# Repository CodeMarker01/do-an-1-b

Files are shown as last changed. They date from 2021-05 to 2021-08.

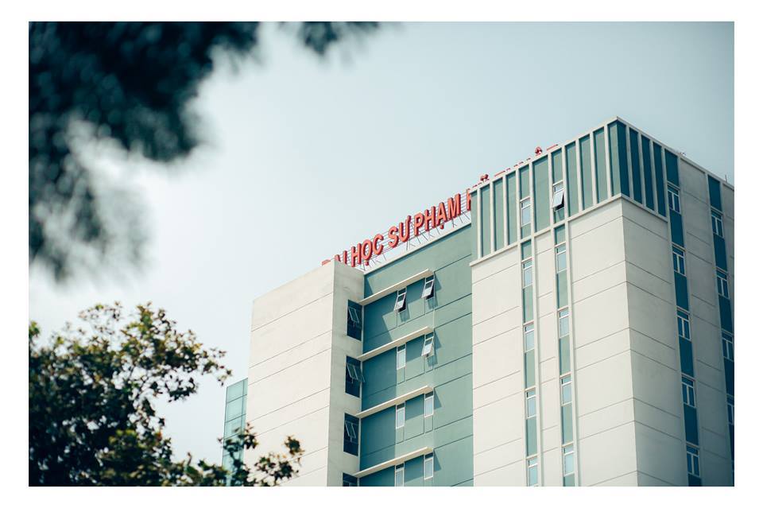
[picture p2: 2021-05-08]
Design HMI/Picture/a/UTE/SPKT1.jpg

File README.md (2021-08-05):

# ĐỒ ÁN TỐT NGHIỆP - PHẠM NHẤT SINH - TRẦN ĐĂNG QUANG
/** Thiết kế và thi công hệ thống chấm công nhân viên **/

1. Source Code phần nhúng: Embedded/Code/DATN_V3_DONE
2. File thiết kế giao diện màn hình HMI: Design HMI/Design/DATN.HMI
3. File thiết kế board mạch: Design Hardware/Design/Source.docx
4. File thiết kế mô hình: Design Model/DATN_sinhquang.dxf
5. File Sever: server
6. Source code phần Web: client

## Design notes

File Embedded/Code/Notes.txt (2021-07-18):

1. R305 giao tiếp ESP32 qua UART2: sửa lại TX: 2 - RX: 4 (trong HardwareSerial.cpp).
2. HMI giao tiếp ESP32 qua UART1: sửa lại nextionSerial: Serial1 (trong NextionCong).
				  xóa nexupdate trong lib nextion

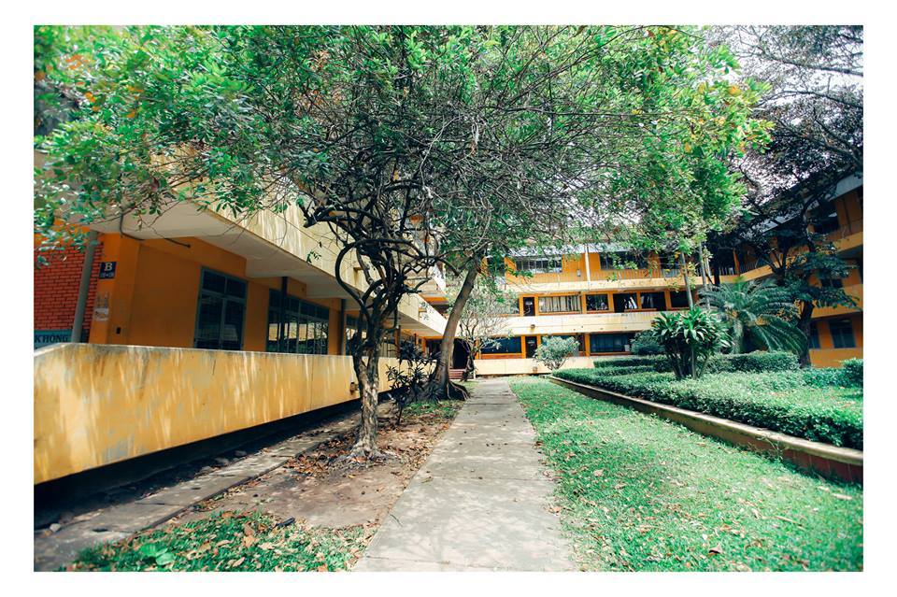
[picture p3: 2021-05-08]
Design HMI/Picture/a/UTE/SPKT5.jpg

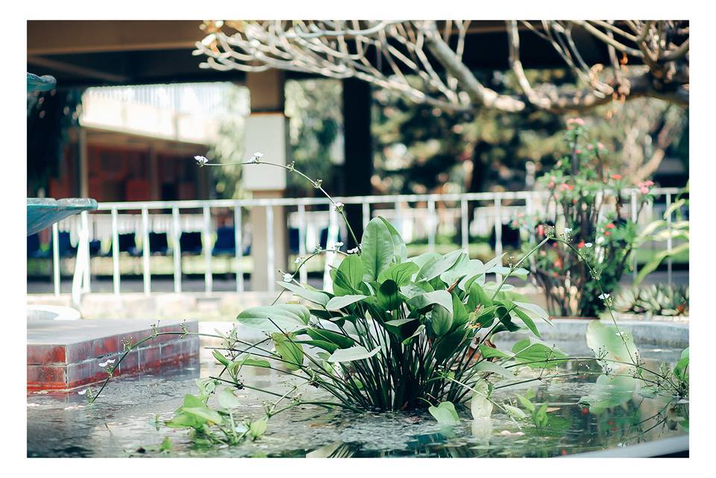
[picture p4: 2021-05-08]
Design HMI/Picture/a/UTE/SPKT2.jpg

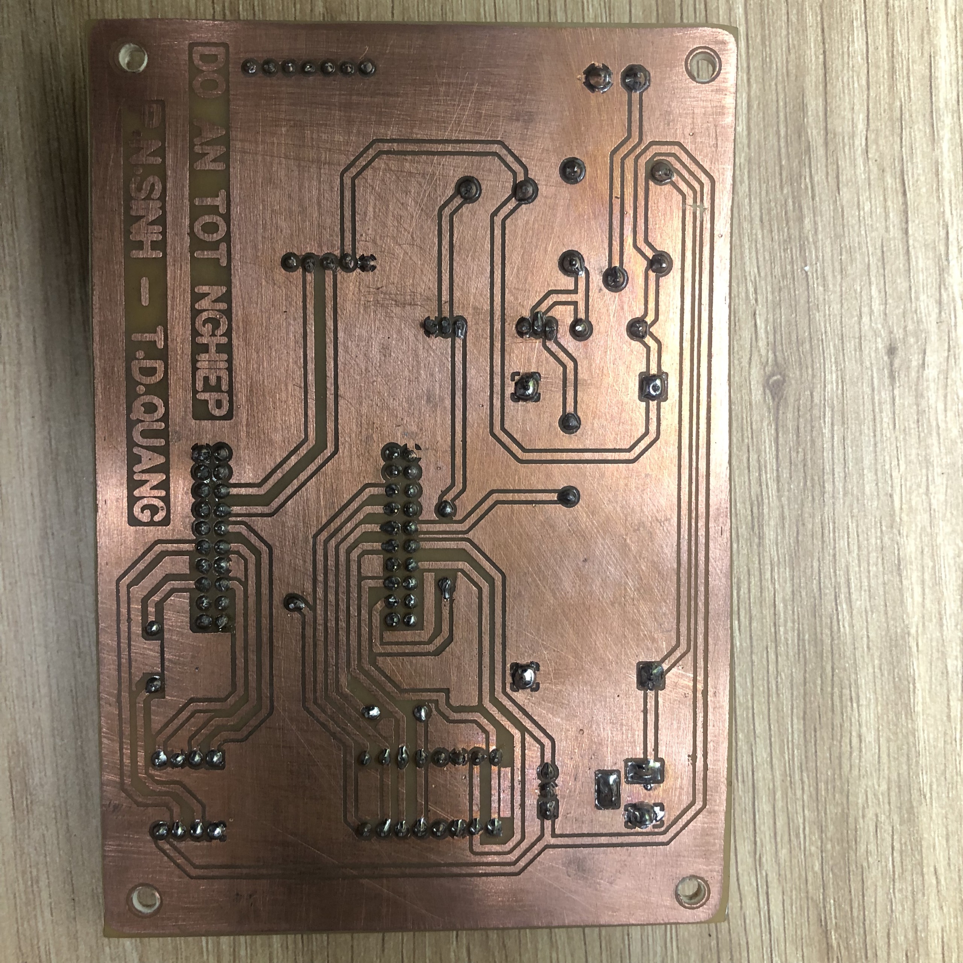
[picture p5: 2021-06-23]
Design Hardware/Image/Actual image/z2544616520501_a6df848a63fc4f655f9d95091a193955.jpg

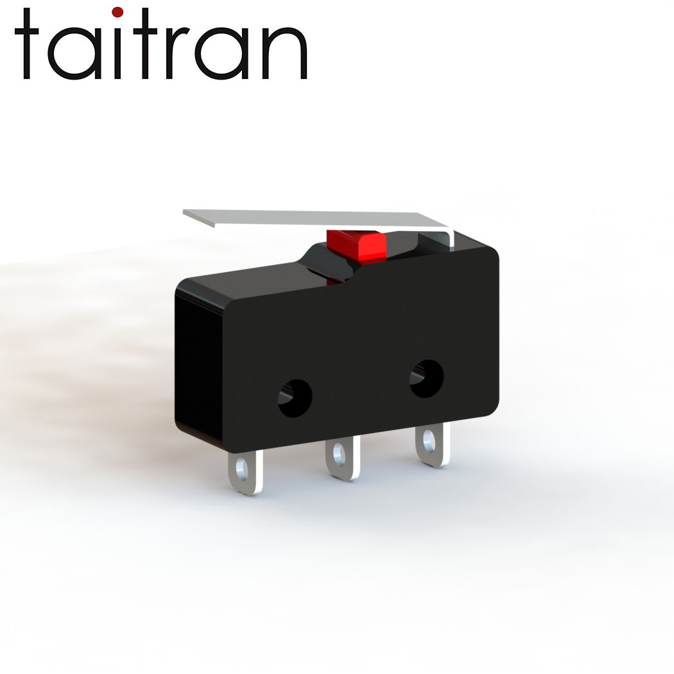
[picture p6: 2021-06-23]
Design Model/Size Module/File 3D module/Picture/cong tat hanh trinh.JPG

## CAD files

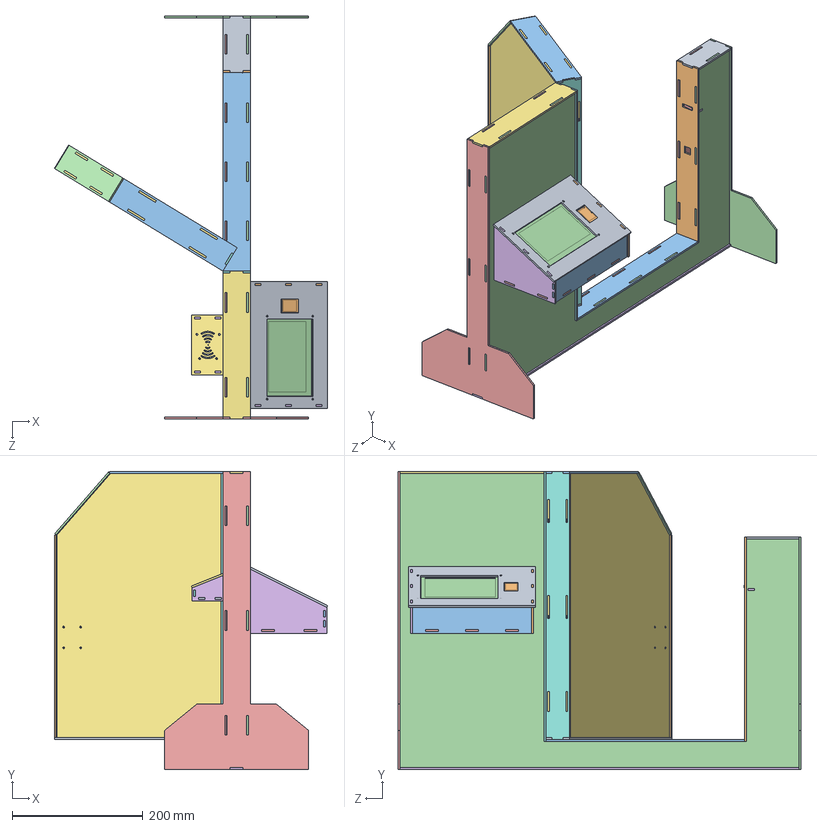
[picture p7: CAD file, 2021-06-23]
Design Model/Autocad/H.SLDASM
418.3 x 456.0 x 616.0 mm
H_mattruoc
H_mathongphai
H_matdoidien
Khungcua_vachtruoc
H_matday
Khungcua_vachday
Khungcua_vachtren
Khungcua_vachcuahongtrai
Khungcua_vachtrennho
Khungcua_vachcuahongphai
Khungcua_vachduoi
Khungcua_vachhongphai
Khungcua_vachhongtrai
H_mathongtrai
cua_vachchinh x 2
cua_vachtrai
cua_vachday
cua_vachphai
cua_vachtren
cua_vachtren1
Khungcua_vachsau
HOPRFID_vachhong x 2
HOPRFID_vachtren
HOPRFID_vachtruoc
HOPRFID_vachday
cam bien van tay
RFID
man hinh nextion
congtachanhtrinh
H_partgancongtachanhtrinh

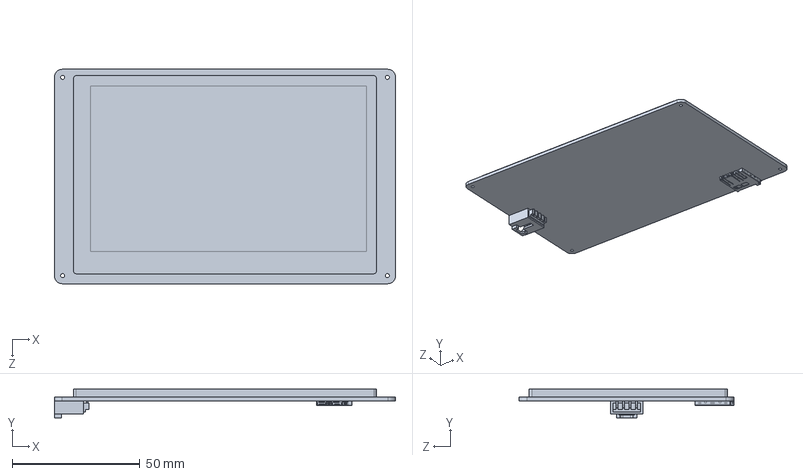
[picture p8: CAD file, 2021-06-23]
Design Model/Autocad/man hinh nextion.SLDPRT
133.5 x 11.2 x 84.0 mm

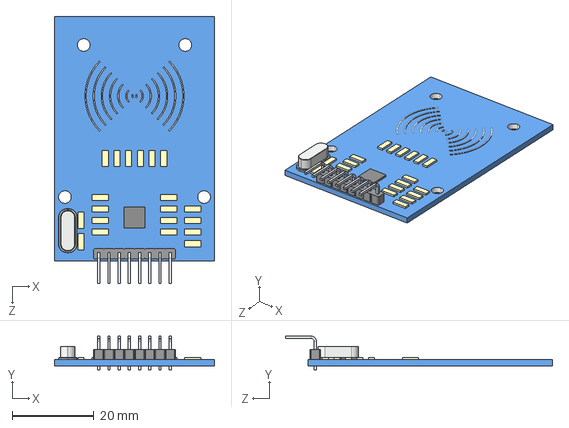
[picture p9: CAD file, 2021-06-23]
Design Model/Autocad/New folder/RC522.STEP
39.2 x 8.30 x 65.5 mm

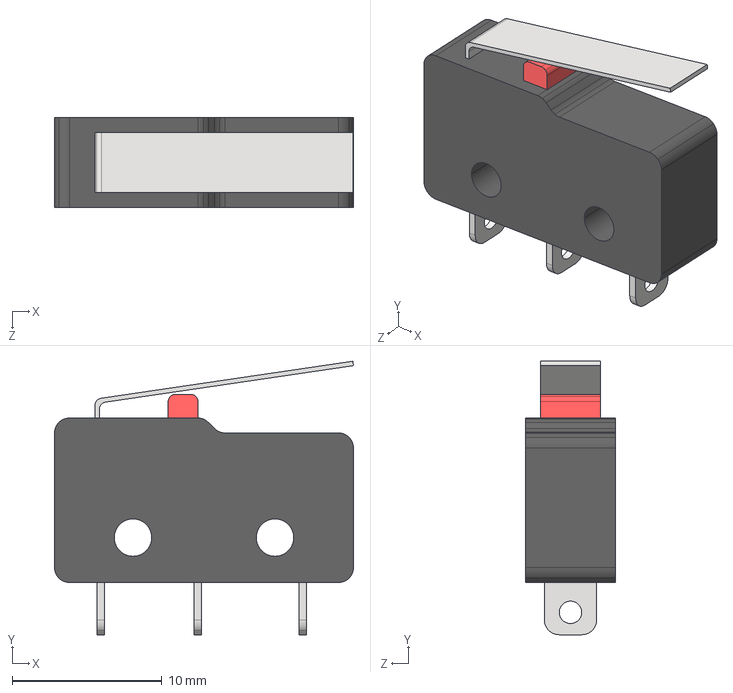
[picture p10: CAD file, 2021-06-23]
Design Model/Autocad/New folder/STEP/cong tat hanh trinh.STEP
20.0 x 18.3 x 6.00 mm

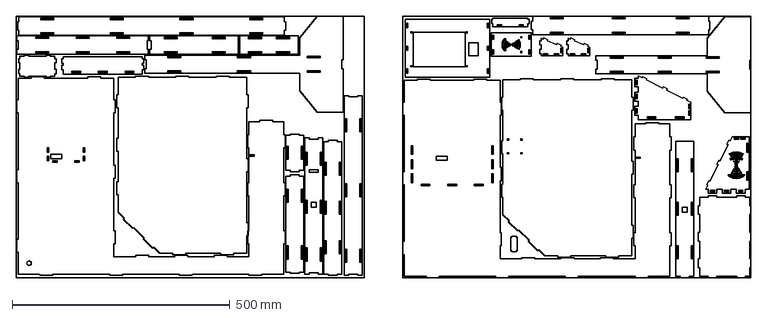
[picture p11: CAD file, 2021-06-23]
Design Model/DATN_sinhquang.dxf
1687.9 x 600.0 mm

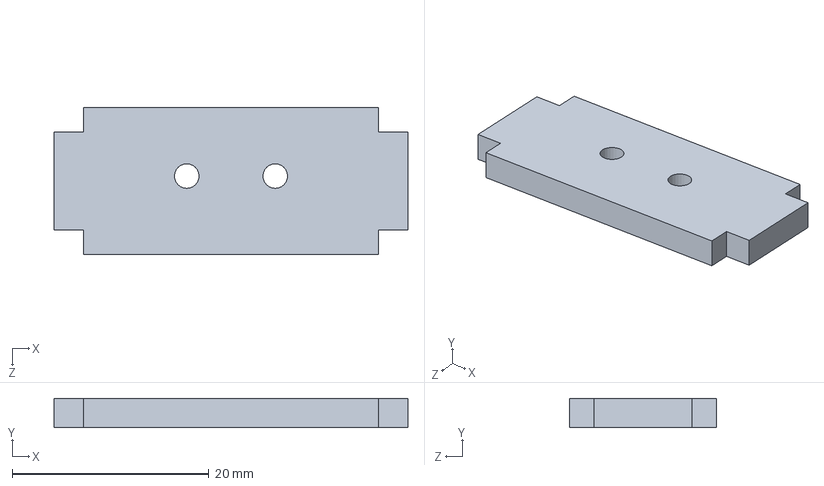
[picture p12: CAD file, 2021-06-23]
Design Model/Autocad/H_partgancongtachanhtrinh.SLDPRT
36.0 x 3.00 x 15.0 mm

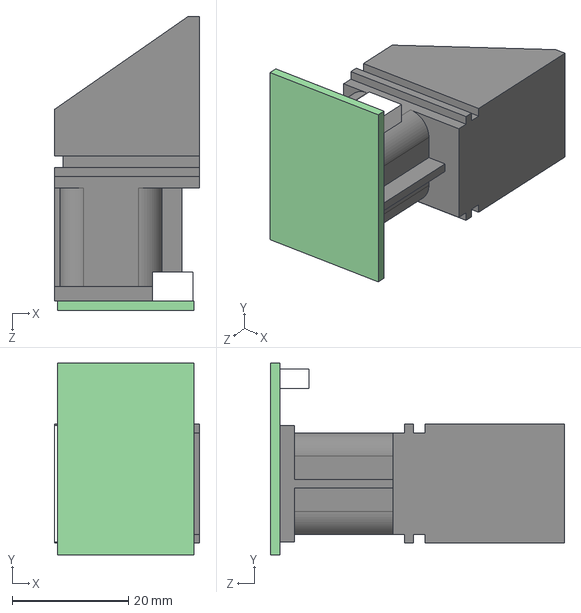
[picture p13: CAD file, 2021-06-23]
Design Model/Size Module/File 3D module/STEP/cam bien van tay.STEP
25.0 x 33.0 x 50.6 mm

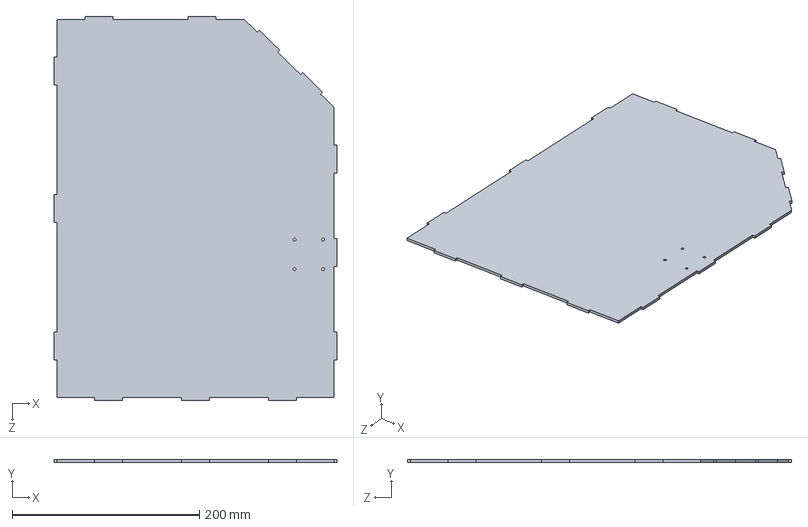
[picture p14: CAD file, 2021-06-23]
Design Model/Autocad/cua_vachchinh.SLDPRT
302.0 x 3.00 x 410.0 mm

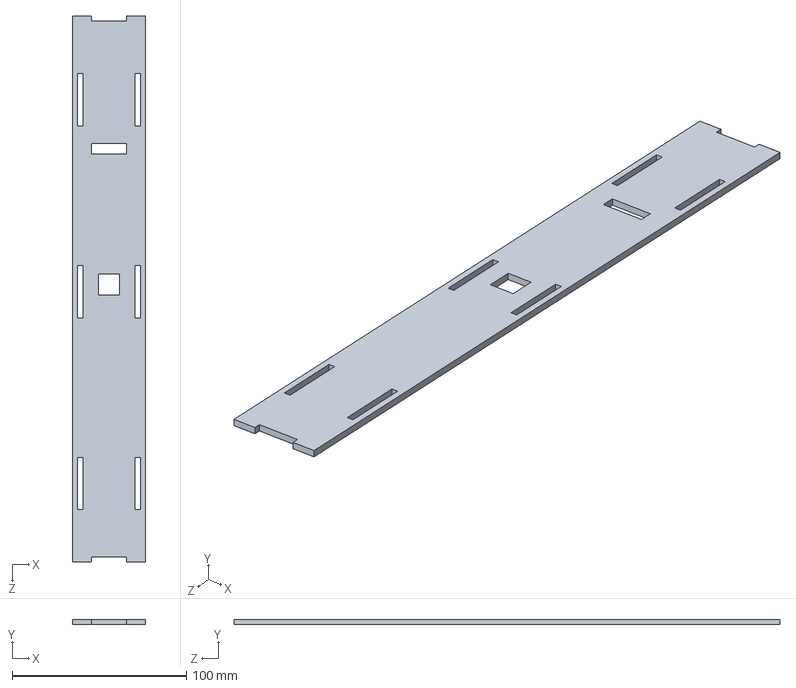
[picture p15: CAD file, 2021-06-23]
Design Model/Autocad/Khungcua_vachcuahongphai.SLDPRT
42.0 x 3.00 x 313.0 mm

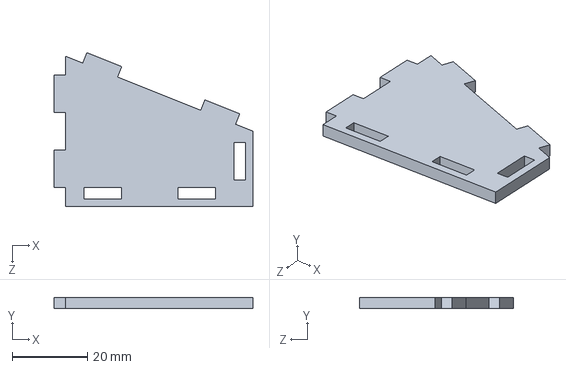
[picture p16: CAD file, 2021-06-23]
Design Model/Autocad/HOPRFID_vachhong.SLDPRT
53.0 x 3.00 x 40.9 mm

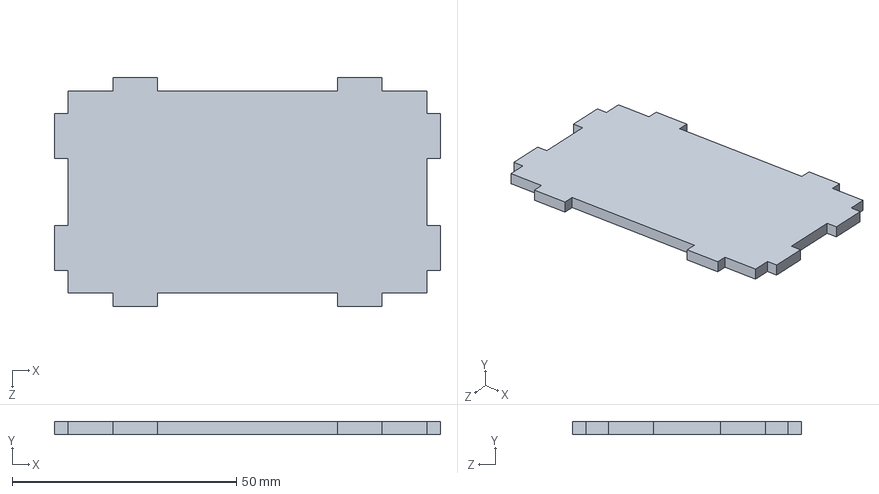
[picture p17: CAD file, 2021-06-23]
Design Model/Autocad/HOPRFID_vachday.SLDPRT
86.0 x 3.00 x 51.0 mm

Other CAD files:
Design Model/Autocad/DATN_sinh.dxf
Design Model/Autocad/DATN_sinh.DWG
Design Model/Autocad/DATN_sinh.SLDDRW
Design Model/Autocad/DATN_sinhct.dxf
Design Model/Autocad/HOPRFID_vachtren.SLDPRT
Design Model/Autocad/HOPRFID_vachtruoc.SLDPRT
Design Model/Autocad/H_matday.SLDPRT
Design Model/Autocad/H_matdoidien.SLDPRT
Design Model/Autocad/H_mathongphai.SLDPRT
Design Model/Autocad/H_mathongtrai.SLDPRT
Design Model/Autocad/H_mattruoc.SLDPRT
Design Model/Autocad/Khungcua_vachcuahongtrai.SLDPRT
Design Model/Autocad/Khungcua_vachday.SLDPRT
Design Model/Autocad/Khungcua_vachduoi.SLDPRT
Design Model/Autocad/Khungcua_vachhongphai.SLDPRT
Design Model/Autocad/Khungcua_vachhongtrai.SLDPRT
Design Model/Autocad/Khungcua_vachsau.SLDPRT
Design Model/Autocad/Khungcua_vachtren.SLDPRT
Design Model/Autocad/Khungcua_vachtrennho.SLDPRT
Design Model/Autocad/Khungcua_vachtruoc.SLDPRT
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

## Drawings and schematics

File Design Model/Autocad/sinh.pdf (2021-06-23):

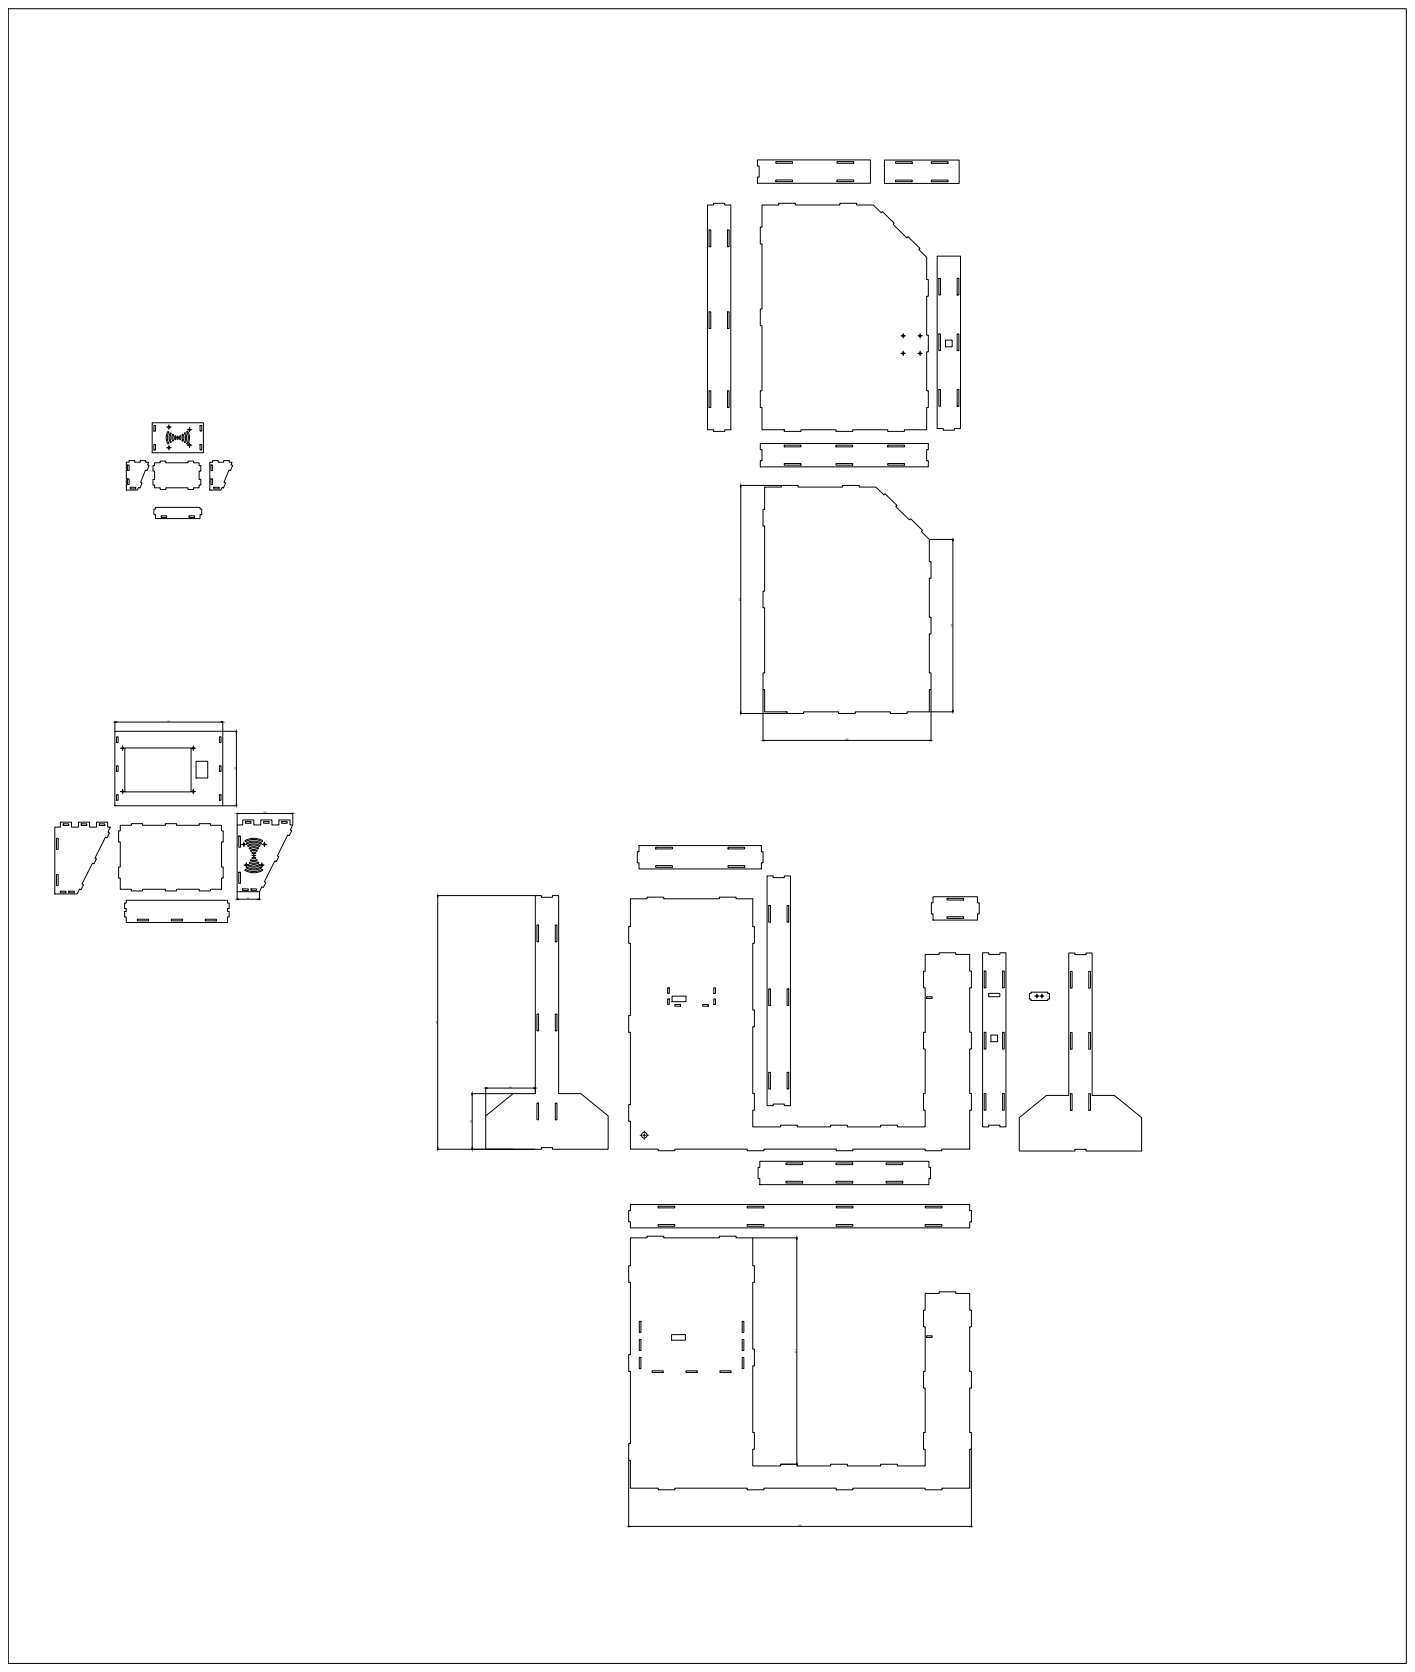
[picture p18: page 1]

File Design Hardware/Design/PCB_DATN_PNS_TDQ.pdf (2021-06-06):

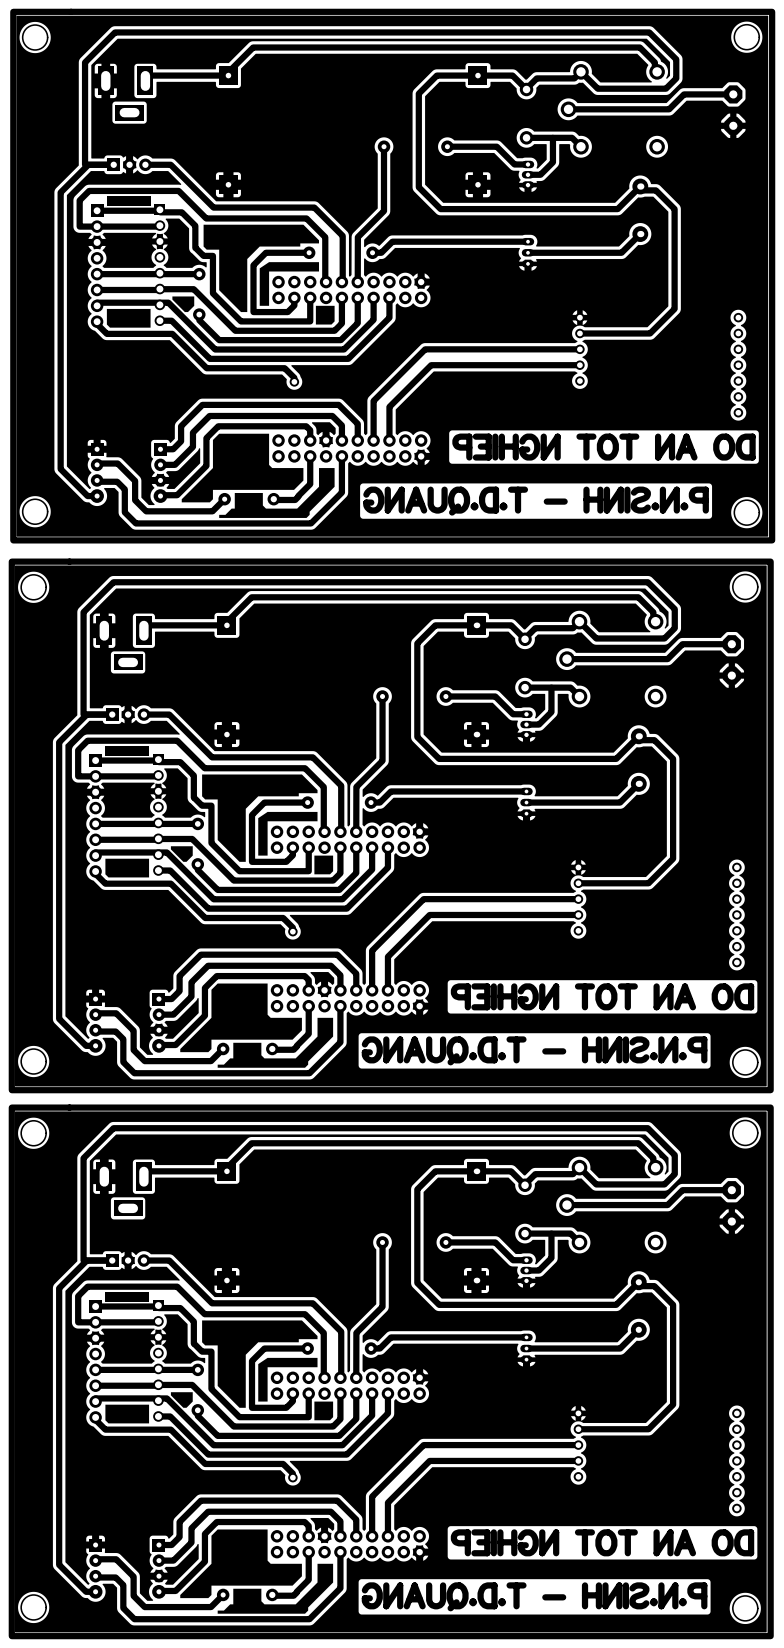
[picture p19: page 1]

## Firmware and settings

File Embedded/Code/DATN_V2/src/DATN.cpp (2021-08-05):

/***
 * Title: Employee attendance system
 * Autor: Sinh Pham
 * Supporter: Quang Tran
 * Issue: 05/04/2021
 ***/
#include <Nextion.h>
#include <Adafruit_Fingerprint.h>
#include <HardwareSerial.h>
#include <SPI.h>
#include <MFRC522.h>
#include <RTClib.h>
#include <WiFi.h>
#include <HTTPClient.h>
#include <Arduino_JSON.h>
#include <Arduino.h>
#include <EEPROM.h>
#define RST_PIN        14
#define SS_PIN1        15
#define SS_PIN         26
#define SENSOR_DOOR    34
#define RELAY          33
#define BUZZER         13
MFRC522 mfrc522(SS_PIN, RST_PIN);
MFRC522 rfid1(SS_PIN1, RST_PIN); 
RTC_DS1307 rtc;
char daysOfTheWeek[7][12] = {"Sunday", "Monday", "Tuesday", "Wednesday", "Thursday", "Friday", "Saturday"};
Adafruit_Fingerprint finger = Adafruit_Fingerprint(&Serial2);

void BUZZER_SWITCH(int dl);
void BUZZER_NOTIFICATION(int dl);
void READ_RFID();
void READ_RFID1();
void READ_RFID2();
int getFingerprintIDez();
uint8_t getFingerprintEnroll();
uint8_t deleteFingerprint(uint8_t id);
void GET_TIME();
void SEND_DATA_STORED();
void SEND_DATA_CHECK();
void SEND_DATA_CREATEDOOR();
void SEND_DATA_CHECKDOOR();
void SEND_DATA_DELETEUSER();

//NEXTION CONTROL ADD USER PAGE
NexRtc  RTC;
NexVariable var0_year = NexVariable(0, 9, "va0");
NexVariable var1_month = NexVariable(0, 10, "va1");
NexVariable var2_day = NexVariable(0, 11, "va2");
NexVariable var3_hour = NexVariable(0, 12, "va3");
NexVariable var4_minute = NexVariable(0, 13, "va4");
NexVariable var5_second = NexVariable(0, 14, "va5");
//PAGE 0
NexText text_time_p0 = NexText(0, 7, "t5"); 
NexText text_connect_p0 = NexText(0, 6, "t4"); 
NexTouch touch_switchpage_p0 = NexButton(0, 1, "m0");
//PAGE 1
NexText text_state_p1 = NexText(1, 1, "t6"); 
NexButton button_user_p1 = NexButton(1, 2, "b0");
NexButton button_admin_p1 = NexButton(1, 3, "b1");
NexRadio  select_checkin_p1 = NexRadio(1, 5, "r0");
NexRadio  select_checkout_p1 = NexRadio(1, 6, "r1");
//PAGE 2
NexText text_state_p2 = NexText(2, 1, "t9"); 
NexText text_inforname_p2 = NexText(2, 4, "t10");
NexText text_infortime_p2 = NexText(2, 6, "t11"); 
NexButton button_fing_p2 = NexButton(2, 2, "b0");
NexButton button_rfid_p2 = NexButton(2, 3, "b1");
//PAGE 3
NexButton button_install_p3 = NexButton(3, 7, "b3");
NexButton button_exitdoor_p3 = NexButton(3, 8, "b4");
//PAGE key_rfid_select 
NexText text_pkrfidsel = NexText(7, 1, "t0");
NexButton button_pkrfidsel = NexButton(7, 10, "b28");
//PAGE key_pass_admin
NexText text_pkpassad = NexText(8, 1, "t0");
NexButton button_pkpassad = NexButton(8, 10, "b28");
//PAGE ADD USER 
NexText text_fing_p4 = NexText(4, 9, "t18"); 
NexText text_rfid_p4 = NexText(4, 10, "t19"); 
NexText text_name_p4 = NexText(4, 11, "t20"); 
NexText text_pos_p4 = NexText(4, 12, "t21"); 
NexText text_gmail_p4 = NexText(4, 13, "t13"); 
//NexText text_username_p4 = NexText(4, 14, "t14"); 
NexText text_pass_p4 = NexText(4, 14, "t15"); 
NexText text_pass2_p4 = NexText(4, 15, "t16"); 
NexText text_infor_p4 = NexText(4, 25, "t17"); 
NexTouch button_fing_p4 = NexButton(4, 16, "m0");
NexTouch button_rfid_p4 = NexButton(4, 17, "m1");
NexButton button_exit_p4 = NexButton(4, 23, "b0");
NexButton button_done_p4 = NexButton(4, 24, "b1");
//PAGE KEYBOARD ADD USER
NexText text_dis_pkeyname = NexText(9, 1, "t0"); 
NexText text_dis_pkeypos = NexText(10, 1, "t0"); 
NexText text_dis_pkeygmail = NexText(11, 1, "t0"); 
//NexText text_dis_pkeyusername = NexText(12, 1, "t0"); 
NexText text_dis_pkeypass = NexText(12, 1, "t0"); 
NexText text_dis_pkeypass2 = NexText(13, 1, "t0"); 
NexButton button_enter_pkeyname = NexButton(9, 10, "b28");
NexButton button_enter_pkeypos = NexButton(10, 10, "b28");
NexButton button_enter_pkeygmail = NexButton(11, 10, "b28");
//NexButton button_enter_pkeyusername = NexButton(12, 10, "b28");
NexButton button_enter_pkeypass = NexButton(12, 10, "b28");
NexButton button_enter_pkeypass2 = NexButton(13, 10, "b28");
//PAGE KEYBOARD DELETE
NexText text_dis_delall = NexText(14, 1, "t0"); 
NexText text_dis_delid = NexText(15, 1, "t0");
NexText text_dis_pdeluser = NexText(5, 4, "t31"); 
NexButton button_enter_pdelall = NexButton(14, 10, "b28");
NexButton button_enter_pdelid = NexButton(15, 10, "b28");
//PAGE SET TAG TEMPORARY
NexText text_rfid_psettemp = NexText(6, 5, "t36"); 
NexText text_pos_psettemp = NexText(6, 6, "t37"); 
NexText text_dur_psettemp = NexText(6, 7, "t38");
NexText text_infor_psettemp = NexText(6, 13, "t39"); 
NexText text_pos_pkeytemp = NexText(17, 1, "t0"); 
NexText text_dur_pkeytemp = NexText(18, 1, "t0"); 
NexTouch button_rfid_psettemp = NexButton(6, 8, "m0");
NexButton button_pos_pkeytemp = NexButton(16, 10, "b28");
NexButton button_dur_pkeytemp = NexButton(17, 10, "b28");
NexButton button_exit_psettemp = NexButton(6, 11, "b0");
NexButton button_done_psettemp = NexButton(6, 12, "b1");
//DEFINE PAGE
NexPage page0 = NexPage(0,0,"wait");
NexPage page1 = NexPage(1,0,"select");
NexPage page2 = NexPage(2,0,"user");
NexPage page3 = NexPage(3,0,"admin");
NexPage page4 = NexPage(4,0,"add_user");
NexPage page5 = NexPage(5,0,"del_user");
NexPage page6 = NexPage(6,0,"set_temp");
NexPage page_key_pass_admin = NexPage(8, 0, "key_pass_admin");

//KHAI BAO BIEN SU DUNG
int  ID_CHECK, ID_STORED, ID_DEL, CHECK_ID_STORED, SELECT_FP_RFID = 0, ENABLE_OPEN = 0, ENA_EXITDOOR = 0;
uint32_t   ENA_CHECKIN, ENA_CHECKOUT;
uint32_t year1, month1, day1, hour1, minute1, second1, year, month, day, hour, minute, second;
uint32_t TIME_SET_HMI[7]; 
String NAME_RESPOND_S = {};
String ENABLE_DOOR = {};
String DELETE_USER_S = {};
byte UID_B[4], UIDC_B[4];
byte moc, mocDel;
char ID_CHECK_C[20], ID_STORED_C[20], USERNAME_DEL_C[20], ID_DEL_C[20], ID_DEL_C2[20], NAME_RESPOND_C[20], Respond_DataCreateUser_C[20], Respond_DataCreateDoor_C[20];
char UID_C[8], UIDC_C[8], TIME_ALL[25], TIME[25]; 
char textname_p4c[20], textpos_p4c[20],textgmail_p4c[20], textpass_p4c[20], textpass2_p4c[20]; 
char textpos_psettempc[20], textdur_psettempc[20], pass_pkrfidselc[15], pass_pkpassadc[8], pass_pdelallc[8];
long previousMillis = 0; 

//DEFINE WIFI
const char *ssid = "TOTOLINK";
const char *password = "Motdentam";
const char *serverCreateUser = "http://192.168.0.3:8000/api/create-users";
const char *serverCreateDoor = "http://192.168.0.3:8000/api/user/create-guest";
const char *serverCheckUser = "http://192.168.0.3:8000/api/user/check-in-out";  
const char *serverCheckDoor = "http://192.168.0.3:8000/api/user/open-door";
const char *serverDeleteUser = "http://192.168.0.3:8000/api/user/delete";

//DEFINE OBJECT TOUCH
NexTouch *nex_listen_list[] = 
{
  &touch_switchpage_p0,
  &button_user_p1,
  &button_admin_p1,
  &button_fing_p2,
  &button_rfid_p2,
  &button_install_p3,
  &button_exitdoor_p3,
  &button_fing_p4,
  &button_rfid_p4,
  &button_enter_pkeyname,
  &button_enter_pkeypos,
  &button_enter_pkeygmail,
  &button_enter_pkeypass,
  &button_enter_pkeypass2,
  &button_exit_p4,
  &button_done_p4,
  &button_enter_pdelall,
  &button_enter_pdelid,
  &button_rfid_psettemp,
  &button_pos_pkeytemp,
  &button_dur_pkeytemp,
  &button_exit_psettemp,
  &button_done_psettemp,
  &button_pkrfidsel,
  &button_pkpassad,
  NULL
}; 

void touch_switchpage_p0_PopCallback(void *ptr)
{
  //RECONNECT WIFI
  if (WiFi.status() != WL_CONNECTED) 
  {
    text_connect_p0.setText("CONNECT: ERROR");
    Serial.println("Reconnecting to WiFi...");
    WiFi.disconnect();
    WiFi.reconnect();
  }
  else 
  {
    text_connect_p0.setText("CONNECT: OK");
    Serial.println("+++++++++++++ok+++++++++++++++++++");
  }
  page1.show();
}
void button_admin_p1_PopCallback(void *ptr)
{
  BUZZER_SWITCH(50);
  page_key_pass_admin.show();
}
void button_user_p1_PopCallback(void *ptr)
{
  select_checkin_p1.getValue(&ENA_CHECKIN);
  select_checkout_p1.getValue(&ENA_CHECKOUT);
  Serial.print("checkin: ");
  Serial.println(ENA_CHECKIN);
  Serial.print("checkout: ");
  Serial.println(ENA_CHECKOUT);
  if( ((ENA_CHECKIN==1) && (ENA_CHECKOUT==0)) || ((ENA_CHECKIN==0) && (ENA_CHECKOUT==1)) )
  {
    BUZZER_SWITCH(50);
    page2.show();  
  }
}
void bfingp2PopCallback(void *ptr) 
{
  SELECT_FP_RFID = 1;
  Serial.println("R305");
  digitalWrite(BUZZER, HIGH);
  delay(50);
  digitalWrite(BUZZER, LOW);
  text_state_p2.setText("ENTER YOUR FINGER");
  unsigned long  time_now = millis();   
  while(millis() < time_now + 5000)
  {
    getFingerprintIDez();
  } 
  Serial.println(ID_CHECK_C);
  if(ID_CHECK == 0) 
  {
    text_inforname_p2.setText("ID ERROR");  
    delay(1500);
  }
  else 
  { 
    SEND_DATA_CHECK();  
    Serial.println("++++++++++++++");
    Serial.println(NAME_RESPOND_C);
  }
  memset(NAME_RESPOND_C, 0, int(20));
  ID_CHECK = 0;
  page1.show();
}
void button_pkrfidsel_PopCallback(void *ptr)
{
  BUZZER_SWITCH(50);
  text_pkrfidsel.getText(pass_pkrfidselc, 20);
  text_pkrfidsel.setText(NULL);
  Serial.println(String(pass_pkrfidselc)); 
  if( (String(pass_pkrfidselc) == "FINGERPRINT ERROR") || (String(pass_pkrfidselc) == "SYSTEM ERROR"))
  {    
    page2.show();
    SELECT_FP_RFID = 2;
    text_state_p2.setText("ENTER YOUR TAG RFID");
    unsigned long  time_now = millis();   
    while(millis() < time_now + 5000)
    {
       READ_RFID();
    } 
    SEND_DATA_CHECK();  
    memset(pass_pkrfidselc, 0, 15);
    memset(UID_C, 0, 8);  
    text_state_p2.setText("SELECT MODE");
    page1.show();
  }
  else 
  {
    page2.show();
    memset(pass_pkrfidselc, 0, 15);
    text_inforname_p2.setText("THE REQUEST NOT CORRECT");
    delay(1000);
    text_inforname_p2.setText("                       ");
    page1.show();
  }
}
//------------------------------- PAGE ADMIN ---------------------------------------//
void button_pkpassad_PopCallback(void *ptr)
{
  text_pkrfidsel.getText(pass_pkpassadc, 8);
  Serial.println(String(pass_pkpassadc));
  if( (String(pass_pkpassadc) == "12345678") || (String(pass_pkpassadc) == "87654321"))
  {
    page3.show();
    BUZZER_SWITCH(50);
    memset(pass_pkpassadc, 0, int(8));
    text_pkrfidsel.setText(NULL);
  }
  else
  {
    page1.show();
    memset(pass_pkpassadc, 0, int(8));
    text_state_p1.setText("SELECT OBJECT");
  }   
}
void button_install_p3_PopCallback(void *ptr)
{
  GET_TIME();
  uint32_t TIME_SET_HMI[7] = {year1, month1, day1, hour1, minute1, second1};  
  RTC.write_rtc_time(TIME_SET_HMI);
  BUZZER_SWITCH(50);
}
void button_exitdoor_p3_PopCallback(void *ptr)
{
  ENA_EXITDOOR = ENA_EXITDOOR + 1;
  if(ENA_EXITDOOR == 2) ENA_EXITDOOR = 0;
}
void bfingp4_PopCallback(void *ptr) 
{
  BUZZER_SWITCH(50);
  text_fing_p4.setText("ENTER YOUR FINGER");
  EEPROM.get(9, ID_STORED); 
  ID_STORED ++;
  EEPROM.put(9, ID_STORED);  
  EEPROM.commit(); 
  if (ID_STORED == 0) 
  {
     return;
  }
  Serial.print("Enrolling ID #");
  Serial.println(ID_STORED);
  while (!getFingerprintEnroll());
  if(CHECK_ID_STORED == 0)
  {
    text_fing_p4.setText("FINGERPRINTS DID NOT MATCH");
    delay(1000);
  }
  else if(CHECK_ID_STORED == 1)
  {
    BUZZER_NOTIFICATION(200);
    text_fing_p4.setText("STORED!");
    delay(1000);
    sprintf(ID_STORED_C, "%d", ID_STORED);
    text_fing_p4.setText(ID_STORED_C);
  }
  else
  {
    text_fing_p4.setText("ERROR");
    delay(1000);
  }
}
void brfidp4_PopCallback(void *ptr)
{
  BUZZER_SWITCH(50);
  unsigned long  time_now = millis(); 
  while(millis() < time_now + 5000)
  {
     READ_RFID();
     text_rfid_p4.setText("ENTER YOUR TAG RFID");
  } 
  text_rfid_p4.setText(UID_C);                          
}
void bnamep5_PopCallback(void *ptr) 
{
  text_dis_pkeyname.getText(textname_p4c, 20);
  Serial.println(textname_p4c);
  text_dis_pkeyname.setText(NULL);
  page4.show();
  text_name_p4.setText(textname_p4c);
}
void bposp6_PopCallback(void *ptr)
{
  text_dis_pkeypos.getText(textpos_p4c, 20);
  Serial.println(textpos_p4c);
  text_dis_pkeypos.setText(NULL);
  page4.show();
  text_pos_p4.setText(textpos_p4c);
}
void bgmailp7_PopCallback(void *ptr) 
{
  text_dis_pkeygmail.getText(textgmail_p4c, 20);
  Serial.println(textgmail_p4c);
  text_dis_pkeygmail.setText(NULL);
  page4.show();
  text_gmail_p4.setText(textgmail_p4c); 
}
void bpassp8_PopCallback(void *ptr)
{
  text_dis_pkeypass.getText(textpass_p4c, 20);
  Serial.println(textpass_p4c);
  text_dis_pkeypass.setText(NULL);
  page4.show();
  text_pass_p4.setText(textpass_p4c); 
}
void bpass2p8_PopCallback(void *ptr)
{
  text_dis_pkeypass2.getText(textpass2_p4c, 20);
  Serial.println(textpass2_p4c);
  text_dis_pkeypass2.setText(NULL);
  page4.show();
  if(String(textpass2_p4c) == String(textpass_p4c))
  {
    text_pass2_p4.setText(textpass2_p4c); 
    Serial.println("CORRECT");
  }
  else
  {
    text_infor_p4.setText("PASSWORD INCORRECT");
    memset(textpass2_p4c, 0, int(20));
    Serial.println("PASS1: ");
    Serial.println(textpass_p4c);
    Serial.println("PASS2: ");
    Serial.println(textpass2_p4c); 
  }
}
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
void loop() 
{
  //CHECK RFID TO OPEN DOOR 
  READ_RFID1();
  READ_RFID2(); 
  if (String(UIDC_C) == NULL)
  {
    Serial.println("NO CARD");  
  }
  else
  {
    SEND_DATA_CHECKDOOR();
    memset(UIDC_C, 0, int(8));
    Serial.println("HAVE CARD"); 
  }
  /* OPEN - CLOSE DOOR*/
  if(ENA_EXITDOOR == 1)
  {
      digitalWrite(RELAY, LOW); //OPEN
      Serial.println("OPEN DOOR");
  } 
  else if(ENA_EXITDOOR == 0)
  {
    if(ENABLE_DOOR == "1" && digitalRead(SENSOR_DOOR) == 0)
    {
      digitalWrite(RELAY, LOW); //OPEN
      Serial.println("OPEN DOOR");
      ENABLE_OPEN = 1;
      ENABLE_DOOR = "0";
    }
    else if(ENABLE_OPEN == 1 && digitalRead(SENSOR_DOOR) == 0) //MAINTAIN
    {
      digitalWrite(RELAY, LOW); //OPEN
      Serial.println("OPEN DOOR");
    }
    else if(digitalRead(SENSOR_DOOR) == 1)
    {
      digitalWrite(RELAY, HIGH); //CLOSE
      Serial.println("CLOSE DOOR");
      ENABLE_OPEN = 0;
      ENABLE_DOOR = "0";
    }
  }
  // LOOP NEXTION
  if(millis() - previousMillis >= 1000)
  {
     previousMillis = millis();
     nexLoop(nex_listen_list);
  }
} 

void BUZZER_SWITCH(int dl)	
{
  digitalWrite(BUZZER, HIGH);
  delay(dl);	
  digitalWrite(BUZZER, LOW);
}

void BUZZER_NOTIFICATION(int dl)		
{
  for(int k=0;k<3;k++)
  {
    digitalWrite(BUZZER, HIGH);
    delay(dl);
    digitalWrite(BUZZER, LOW);
    delay(dl);
  }		
}
void READ_RFID()
{
  SPI.begin(); 
  mfrc522.PCD_Init(); 
  // Reset the loop if no new card present on the sensor/reader.
  if ( ! mfrc522.PICC_IsNewCardPresent()) 
  {
    return;
  }
  // Select one of the cards
  if ( ! mfrc522.PICC_ReadCardSerial()) 
  {
    return;
  }
  Serial.println("ID CHECK: ");
  for (byte i = 0; i < mfrc522.uid.size; i++)
  {
    UID_B[i] = mfrc522.uid.uidByte[i];
  }
  byte UID_SIZE = sizeof(UID_B);
  //COVERT BYTE TO CHAR
  for (int y = 0; y < UID_SIZE; y++)
  {
    sprintf(&UID_C[y * 2], "%02X", UID_B[y]);
  }
  digitalWrite(BUZZER, HIGH);
  delay(50);
  digitalWrite(BUZZER, LOW);
  Serial.println(UID_C);
  Serial.println("");
  mfrc522.PICC_HaltA();
  mfrc522.PCD_StopCrypto1(); 
  SPI.end(); 
}

void READ_RFID1()
{
  SPI.begin(); 
  mfrc522.PCD_Init(); 
  // Reset the loop if no new card present on the sensor/reader.
  if ( ! mfrc522.PICC_IsNewCardPresent()) 
  {
    return;
  }
  // Select one of the cards
  if ( ! mfrc522.PICC_ReadCardSerial()) 
  {
    return;
  }
  Serial.println("READER 1: ");
  for (byte i = 0; i < mfrc522.uid.size; i++)
  {
    UIDC_B[i] = mfrc522.uid.uidByte[i];
  }
  byte UIDC_SIZE = sizeof(UIDC_B);
  memset(UIDC_C, 0, sizeof(UIDC_SIZE));
  //COVERT BYTE TO CHAR
  for (int y = 0; y < UIDC_SIZE; y++)
  {
    sprintf(&UIDC_C[y * 2], "%02X", UIDC_B[y]);
  }
  digitalWrite(BUZZER, HIGH);
  delay(50);
  digitalWrite(BUZZER, LOW);
  Serial.println(UIDC_C);
  Serial.println("");
  mfrc522.PICC_HaltA();
  mfrc522.PCD_StopCrypto1(); 
  SPI.end(); 
}

void READ_RFID2()
{
  SPI.begin(); 
  rfid1.PCD_Init(); 
  if ( ! rfid1.PICC_IsNewCardPresent()) 
  {
  return;
  }
  if ( ! rfid1.PICC_ReadCardSerial()) 
  {
  return;
  }
  Serial.println("READER 2: ");
  for (byte i = 0; i < rfid1.uid.size; i++)
  {
    UIDC_B[i] = rfid1.uid.uidByte[i];
  }
  byte UIDC_SIZE = sizeof(UIDC_B);
  memset(UIDC_C, 0, sizeof(UIDC_SIZE));
  //COVERT BYTE TO CHAR
  for (int y = 0; y < UIDC_SIZE; y++)
  {
    sprintf(&UIDC_C[y * 2], "%02X", UIDC_B[y]);
  }
  digitalWrite(BUZZER, HIGH);
  delay(50);
  digitalWrite(BUZZER, LOW);
  Serial.println(UIDC_C);
  Serial.println("");
  rfid1.PICC_HaltA();
  rfid1.PCD_StopCrypto1();  
  SPI.end();
}
// CHECK FINGER: returns -1 if failed, otherwise returns ID #
int getFingerprintIDez() 
{
  uint8_t p = finger.getImage();
  if (p != FINGERPRINT_OK)  return -1;
  p = finger.image2Tz();
  if (p != FINGERPRINT_OK)  return -1;
  p = finger.fingerFastSearch();
  if (p != FINGERPRINT_OK)  return -1;
  // found a match!
  Serial.print("P:"); Serial.println(finger.getImage());
  Serial.print("Found ID #"); Serial.print(finger.fingerID);
  Serial.print(" with confidence of "); Serial.println(finger.confidence);
  ID_CHECK = finger.fingerID;
}
//ADD FINGER
uint8_t getFingerprintEnroll() 
{
  int p = -1;
  Serial.print("Waiting for valid finger to enroll as #"); Serial.println(ID_STORED);
  while (p != FINGERPRINT_OK) {
    p = finger.getImage();
    switch (p) {
    case FINGERPRINT_OK:
      Serial.println("Image taken");
      break;
    case FINGERPRINT_NOFINGER:
      Serial.println(".");
      break;
    case FINGERPRINT_PACKETRECIEVEERR:
      Serial.println("Communication error");
      break;
    case FINGERPRINT_IMAGEFAIL:
      Serial.println("Imaging error");
      break;
    default:
      Serial.println("Unknown error");
      break;
    }
  }
  // OK success!
  p = finger.image2Tz(1);
  switch (p) {
    case FINGERPRINT_OK:
      Serial.println("Image converted");
      break;
    case FINGERPRINT_IMAGEMESS:
      Serial.println("Image too messy");
      return p;
    case FINGERPRINT_PACKETRECIEVEERR:
      Serial.println("Communication error");
      return p;
    case FINGERPRINT_FEATUREFAIL:
      Serial.println("Could not find fingerprint features");
      return p;
    case FINGERPRINT_INVALIDIMAGE:
      Serial.println("Could not find fingerprint features");
      return p;
    default:
      Serial.println("Unknown error");
      return p;
  }
  Serial.println("Remove finger");
  delay(2000);
  p = 0;
  while (p != FINGERPRINT_NOFINGER) {
    p = finger.getImage();
  }
  Serial.print("ID "); Serial.println(ID_STORED);
  p = -1;
  Serial.println("Place same finger again");
  while (p != FINGERPRINT_OK) {
    p = finger.getImage();
    switch (p) {
    case FINGERPRINT_OK:
      Serial.println("Image taken");
      break;
    case FINGERPRINT_NOFINGER:
      Serial.print(".");
      break;
    case FINGERPRINT_PACKETRECIEVEERR:
      Serial.println("Communication error");
      break;
    case FINGERPRINT_IMAGEFAIL:
      Serial.println("Imaging error");
      break;
    default:
      Serial.println("Unknown error");
      break;
    }
  }
  // OK success!
  p = finger.image2Tz(2);
  switch (p) {
    case FINGERPRINT_OK:
      Serial.println("Image converted");
      break;
    case FINGERPRINT_IMAGEMESS:
      Serial.println("Image too messy");
      return p;
    case FINGERPRINT_PACKETRECIEVEERR:
      Serial.println("Communication error");
      return p;
    case FINGERPRINT_FEATUREFAIL:
      Serial.println("Could not find fingerprint features");
      return p;
    case FINGERPRINT_INVALIDIMAGE:
      Serial.println("Could not find fingerprint features");
      return p;
    default:
      Serial.println("Unknown error");
      return p;
  }
  // OK converted!
  Serial.print("Creating model for #");  Serial.println(ID_STORED);
  p = finger.createModel();
  if (p == FINGERPRINT_OK) {
    Serial.println("Prints matched!");
  } else if (p == FINGERPRINT_PACKETRECIEVEERR) {
    Serial.println("Communication error");
    return p;
  } else if (p == FINGERPRINT_ENROLLMISMATCH) 
  {
    Serial.println("Fingerprints did not match");
    CHECK_ID_STORED = 0;
    return p;
  } else {
    Serial.println("Unknown error");
    return p;
  }
  Serial.print("ID "); Serial.println(ID_STORED);
  p = finger.storeModel(ID_STORED);
  if (p == FINGERPRINT_OK)
  {
    Serial.println("Stored!");
    CHECK_ID_STORED = 1;
  } else if (p == FINGERPRINT_PACKETRECIEVEERR) {
    Serial.println("Communication error");
    return p;
  } else if (p == FINGERPRINT_BADLOCATION) {
    Serial.println("Could not store in that location");
    return p;
  } else if (p == FINGERPRINT_FLASHERR) {
    Serial.println("Error writing to flash");
    return p;
  } else {
    Serial.println("Unknown error");
    return p;
  }
  return true;
}
//DELETE FINGER 
uint8_t deleteFingerprint(uint8_t id) 
{
  uint8_t p = -1;
  p = finger.deleteModel(id);
  if (p == FINGERPRINT_OK) {
    Serial.println("Deleted!");
  } else if (p == FINGERPRINT_PACKETRECIEVEERR) {
    Serial.println("Communication error");
    return p;
  } else if (p == FINGERPRINT_BADLOCATION) {
    Serial.println("Could not delete in that location");
    return p;
  } else if (p == FINGERPRINT_FLASHERR) {
    Serial.println("Error writing to flash");
    return p;
  } else {
    Serial.print("Unknown error: 0x"); Serial.println(p, HEX);
    return p;
  }
}

void GET_TIME()
{
  DateTime now = rtc.now();
  sprintf(TIME,"%04d-%02d-%02dT%02d:%02d:%02d",now.year(),now.month(), now.day(),now.hour(),now.minute(),now.second());
  sprintf(TIME_ALL,"TIME: %02d:%02d:%02d %02d/%02d/%04d ", now.hour(), now.minute(), now.second(), now.day(), now.month(), now.year());
  year1 = now.year();
  month1 = now.month();
  day1 = now.day();
  hour1 = now.hour();
  minute1 = now.minute();
  second1 = now.second();
}
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

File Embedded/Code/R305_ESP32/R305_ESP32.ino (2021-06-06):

/***************************************************
  This is an example sketch for our optical Fingerprint sensor

  Designed specifically to work with the Adafruit BMP085 Breakout
  ----> http://www.adafruit.com/products/751

  These displays use TTL Serial to communicate, 2 pins are required to
  interface
  Adafruit invests time and resources providing this open source code,
  please support Adafruit and open-source hardware by purchasing
  products from Adafruit!

  Written by Limor Fried/Ladyada for Adafruit Industries.
  BSD license, all text above must be included in any redistribution
 ****************************************************/

#include <Adafruit_Fingerprint.h>
#include <HardwareSerial.h>

#if (defined(__AVR__) || defined(ESP8266)) && !defined(__AVR_ATmega2560__)
// For UNO and others without hardware serial, we must use software serial...
// pin #2 is IN from sensor (GREEN wire)
// pin #3 is OUT from arduino  (WHITE wire)
// Set up the serial port to use softwareserial..
SoftwareSerial mySerial(2, 3);

#else
// On Leonardo/M0/etc, others with hardware serial, use hardware serial!
// #0 is green wire, #1 is white
#define mySerial Serial2

#endif

//Adafruit_Fingerprint finger = Adafruit_Fingerprint(&Serial1);
Adafruit_Fingerprint finger = Adafruit_Fingerprint(&mySerial);

uint8_t id;

void setup()
{
  Serial.begin(9600);
  //Serial2.begin(115200);
  while (!Serial);  // For Yun/Leo/Micro/Zero/...
  delay(100);
  Serial.println("\n\nAdafruit Fingerprint sensor enrollment");

  // set the data rate for the sensor serial port
  finger.begin(57600);

  if (finger.verifyPassword()) {
    Serial.println("Found fingerprint sensor!");
  } else {
    Serial.println("Did not find fingerprint sensor :(");
    while (1) { delay(1); }
  }

  Serial.println(F("Reading sensor parameters"));
  finger.getParameters();
  Serial.print(F("Status: 0x")); Serial.println(finger.status_reg, HEX);
  Serial.print(F("Sys ID: 0x")); Serial.println(finger.system_id, HEX);
  Serial.print(F("Capacity: ")); Serial.println(finger.capacity);
  Serial.print(F("Security level: ")); Serial.println(finger.security_level);
  Serial.print(F("Device address: ")); Serial.println(finger.device_addr, HEX);
  Serial.print(F("Packet len: ")); Serial.println(finger.packet_len);
  Serial.print(F("Baud rate: ")); Serial.println(finger.baud_rate);
}

uint8_t readnumber(void) {
  uint8_t num = 0;

  while (num == 0) {
    while (! Serial.available());
    num = Serial.parseInt();
  }
  return num;
}

void loop()                     // run over and over again
{
  Serial.println("Ready to enroll a fingerprint!");
  Serial.println("Please type in the ID # (from 1 to 127) you want to save this finger as...");
  id = readnumber();
  if (id == 0) {// ID #0 not allowed, try again!
     return;
  }
  Serial.print("Enrolling ID #");
  Serial.println(id);

  while (!  getFingerprintEnroll() );
}

uint8_t getFingerprintEnroll() {

  int p = -1;
  Serial.print("Waiting for valid finger to enroll as #"); Serial.println(id);
  while (p != FINGERPRINT_OK) {
    p = finger.getImage();
    switch (p) {
    case FINGERPRINT_OK:
      Serial.println("Image taken");
      break;
    case FINGERPRINT_NOFINGER:
      Serial.println(".");
      break;
    case FINGERPRINT_PACKETRECIEVEERR:
      Serial.println("Communication error");
      break;
    case FINGERPRINT_IMAGEFAIL:
      Serial.println("Imaging error");
      break;
    default:
      Serial.println("Unknown error");
      break;
    }
  }

  // OK success!

  p = finger.image2Tz(1);
  switch (p) {
    case FINGERPRINT_OK:
      Serial.println("Image converted");
      break;
    case FINGERPRINT_IMAGEMESS:
      Serial.println("Image too messy");
      return p;
    case FINGERPRINT_PACKETRECIEVEERR:
      Serial.println("Communication error");
      return p;
    case FINGERPRINT_FEATUREFAIL:
      Serial.println("Could not find fingerprint features");
      return p;
    case FINGERPRINT_INVALIDIMAGE:
      Serial.println("Could not find fingerprint features");
      return p;
    default:
      Serial.println("Unknown error");
      return p;
  }

  Serial.println("Remove finger");
  delay(2000);
  p = 0;
  while (p != FINGERPRINT_NOFINGER) {
    p = finger.getImage();
  }
  Serial.print("ID "); Serial.println(id);
  p = -1;
  Serial.println("Place same finger again");
  while (p != FINGERPRINT_OK) {
    p = finger.getImage();
    switch (p) {
    case FINGERPRINT_OK:
      Serial.println("Image taken");
      break;
    case FINGERPRINT_NOFINGER:
      Serial.print(".");
      break;
    case FINGERPRINT_PACKETRECIEVEERR:
      Serial.println("Communication error");
      break;
    case FINGERPRINT_IMAGEFAIL:
      Serial.println("Imaging error");
      break;
    default:
      Serial.println("Unknown error");
      break;
    }
  }

  // OK success!

  p = finger.image2Tz(2);
  switch (p) {
    case FINGERPRINT_OK:
      Serial.println("Image converted");
      break;
    case FINGERPRINT_IMAGEMESS:
      Serial.println("Image too messy");
      return p;
    case FINGERPRINT_PACKETRECIEVEERR:
      Serial.println("Communication error");
      return p;
    case FINGERPRINT_FEATUREFAIL:
      Serial.println("Could not find fingerprint features");
      return p;
    case FINGERPRINT_INVALIDIMAGE:
      Serial.println("Could not find fingerprint features");
      return p;
    default:
      Serial.println("Unknown error");
      return p;
  }

  // OK converted!
  Serial.print("Creating model for #");  Serial.println(id);

  p = finger.createModel();
  if (p == FINGERPRINT_OK) {
    Serial.println("Prints matched!");
  } else if (p == FINGERPRINT_PACKETRECIEVEERR) {
    Serial.println("Communication error");
    return p;
  } else if (p == FINGERPRINT_ENROLLMISMATCH) {
    Serial.println("Fingerprints did not match");
    return p;
  } else {
    Serial.println("Unknown error");
    return p;
  }

  Serial.print("ID "); Serial.println(id);
  p = finger.storeModel(id);
  if (p == FINGERPRINT_OK) {
    Serial.println("Stored!");
  } else if (p == FINGERPRINT_PACKETRECIEVEERR) {
    Serial.println("Communication error");
    return p;
  } else if (p == FINGERPRINT_BADLOCATION) {
    Serial.println("Could not store in that location");
    return p;
  } else if (p == FINGERPRINT_FLASHERR) {
    Serial.println("Error writing to flash");
    return p;
  } else {
    Serial.println("Unknown error");
    return p;
  }

  return true;
}

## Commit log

2021-05-28 Update 28/-5/2021
    - Design PCB
    [BOM_PCB_2021-05-28.csv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]
2021-06-22 Update 22/06/2021
    - Update code embedded V2
    [BOM_PCB_2021-05-28.csv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]
2021-06-22 Update Model
    [DATN_sinh.DWG, DATN_sinh.SLDDRW, DATN_sinh.dxf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]
2021-07-18 Update 18/07/2021
    Clean up folder
    [DATN_sinhct.dxf]
2021-07-23 BE: update new delete feature and chart in User.js
    [data.csv]
2021-07-24 implement features: export data and fingerprint error
    [data.csv]
2021-08-05 Update 05/08/2021
    Done
    [data.csv]
